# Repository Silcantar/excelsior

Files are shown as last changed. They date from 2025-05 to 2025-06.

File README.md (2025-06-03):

# *Excelsior*
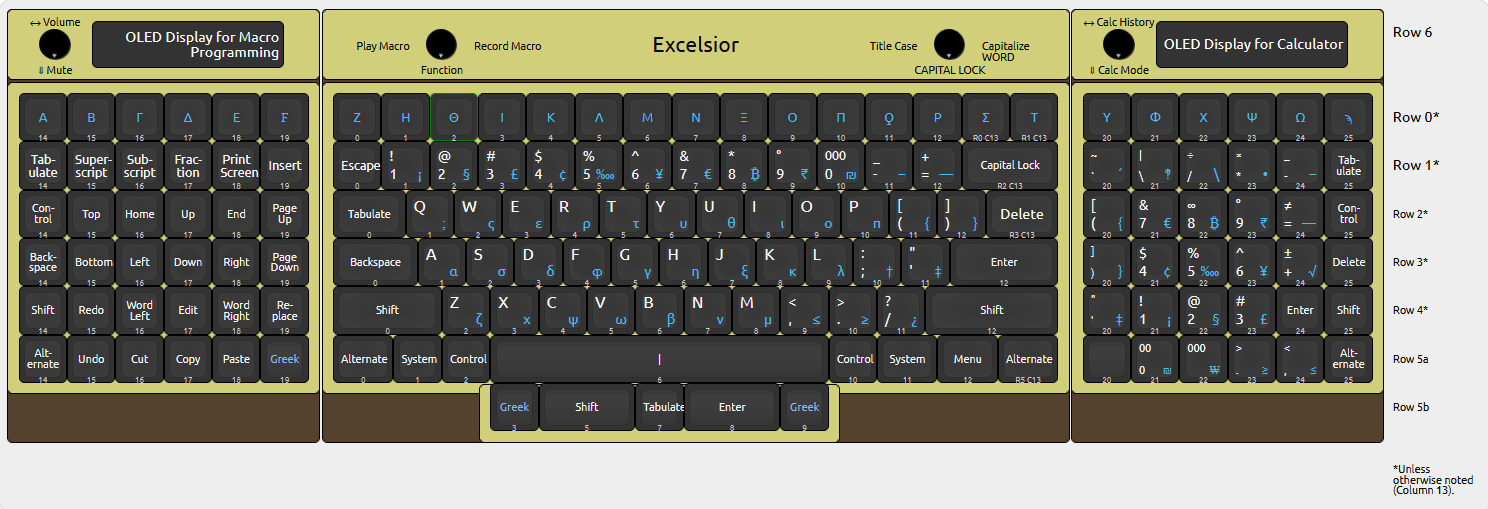
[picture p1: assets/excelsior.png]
Excelsior
>
>Tentative layout and design for *Excelsior*.

*Excelsior* is a 150% (153 keys) 3-section hand-wired keyboard (optionally) using uniform keycaps in a curved plate.

The main section is based on a standard ANSI 60% keyboard, but with a row of 15 function/programmable-macro keys at the top and 5 keys below the 7u spacebar.

The peripheral sections are each 6x6 ortholinear boards and can be placed on either side of the main section, including placing both on the same side of the main. They are connected to the main section by 20-pin pogo pin connectors either directly or via a custom cable. In the default keymap one section is an extended numpad and the other is a large navigation/macro pad. The top row of each peripheral is dedicated to additional function/programmable-macro keys for a total of 27.

The microcontroller is a Pimoroni PGA2350 board located in the main section. The matrix for the main section is wired directly to the controller board, while the I/O for the peripheral sections is handled by an MCP23017 I/O expander in each section communicating with the controller via I²C. The connections between the sections carry the signals necessary for both I²C and for SPI, plus several spare lines for interrupts, chip selects, or other I/O.

The matrix of the main section also has a seventh row that can be used for up to 14 momentary, toggle, or rotary switches on the top bezel of the keyboard. Note that the keys below the spacebar are on the sixth (spacebar) row of the matrix, so the seventh row is completely open.

Because of the massive number of GPIO pins on the PGA2350 and the I/O expanders, there is ample spare I/O for any functionality you could possibly want, from displays, encoders, LEDs, etc.

Because QMK does not currently support the RP2350 or displays larger than 128×64, I am planning to use KMK for the firmware.

For those interested, I have designed a [custom set](https://yuzukeycaps.com/c/4633754e-42e4-428c-9306-6221ce11477c)[^1] of KAM keycaps with a white-on-black-with-blue-accents *Wall Street Journal*-inspired aesthetic for *Excelsior* at YUZU Keycaps. They also feature secondary legends for a Greek alphabet/symbol layer and the macro keys are labeled with Greek numerals. There are a number of extra keys for alternative layouts too. Since the keycaps have a uniform profile any key can be placed on any row.

[^1]: If the link does not work, you can import [this JSON file](keycaps/Excelsior.json) to YUZU

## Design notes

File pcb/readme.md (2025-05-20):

This is a hand-wired build, so the "PCBs" here are not meant for production. I am using them to select and record the necessary components and to verify that the wiring topology is feasible.

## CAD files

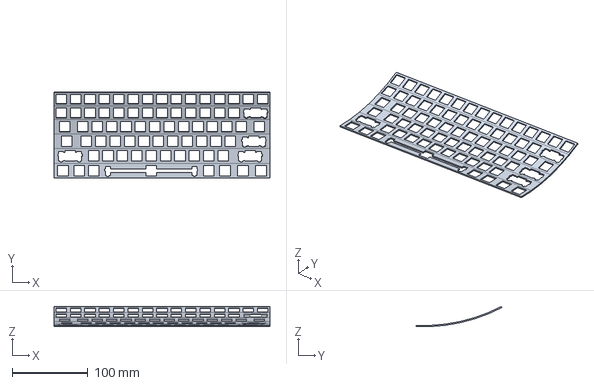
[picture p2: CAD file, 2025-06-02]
case/case.FCStd
285.0 x 113.6 x 26.6 mm

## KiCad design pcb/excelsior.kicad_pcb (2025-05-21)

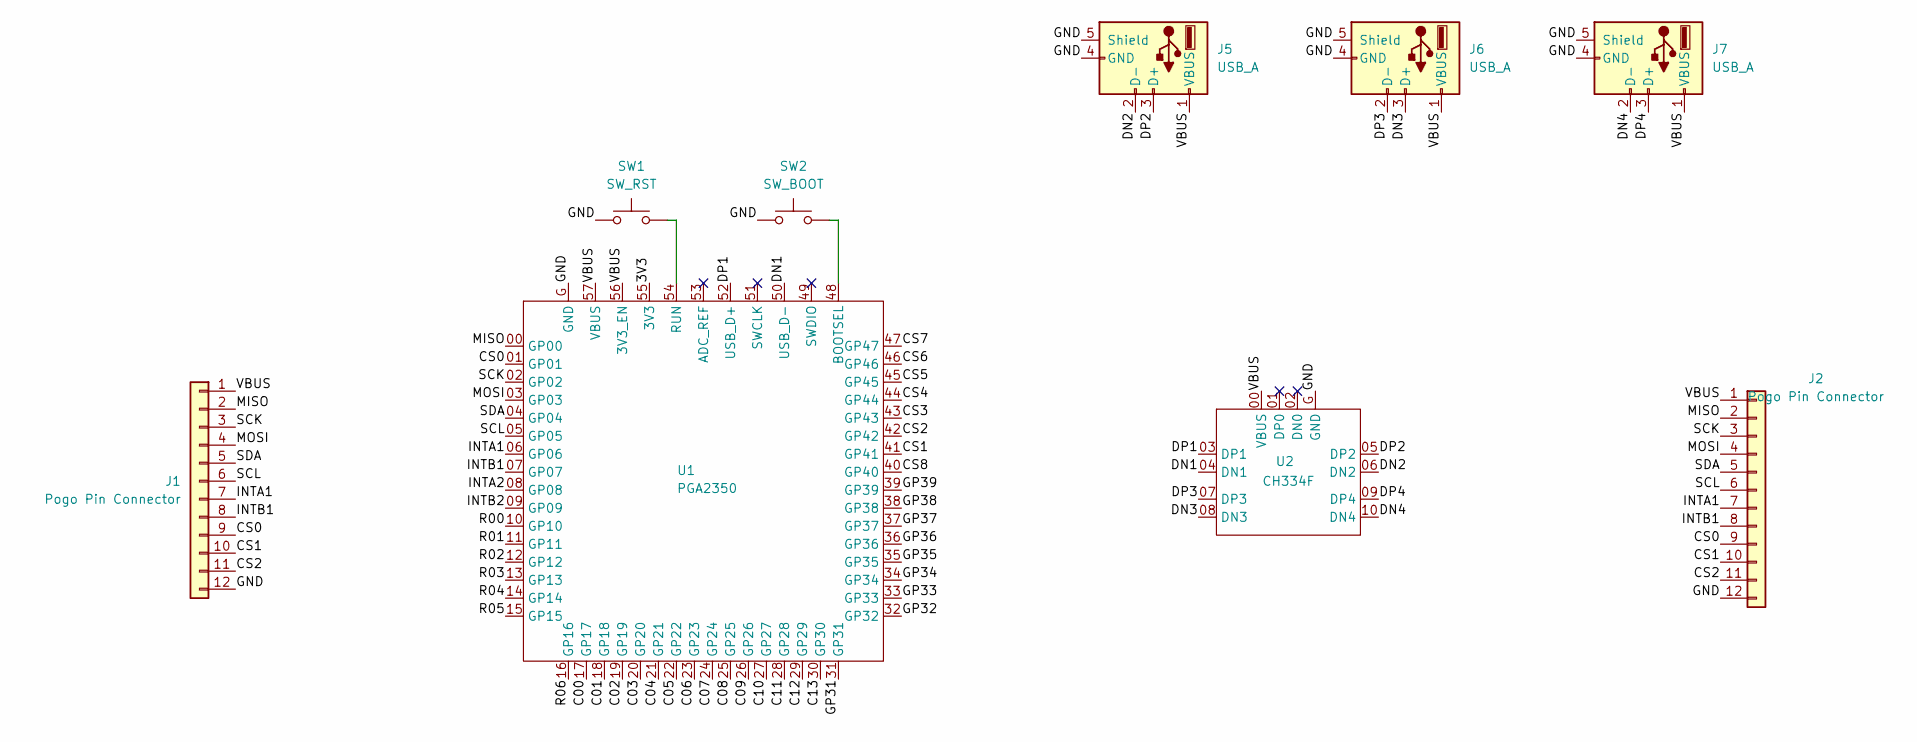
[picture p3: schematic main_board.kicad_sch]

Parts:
J1, J2: Pogo Pin Connector; PinHeader_1x12_P2.54mm_Vertical
J5, J6, J7: USB_A; USB_A_Molex_67643_Horizontal
SW1: SW_RST; SW_PUSH_6mm
SW2: SW_BOOT; SW_PUSH_6mm
U1: PGA2350
U2: CH334F; USB_Hub

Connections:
/Main Board/3V3: U1.55 (3V3)
/Main Board/C00: U1.17 (GP17)
/Main Board/C01: U1.18 (GP18)
/Main Board/C02: U1.19 (GP19)
/Main Board/C03: U1.20 (GP20)
/Main Board/C04: U1.21 (GP21)
/Main Board/C05: U1.22 (GP22)
/Main Board/C06: U1.23 (GP23)
/Main Board/C07: U1.24 (GP24)
/Main Board/C08: U1.25 (GP25)
/Main Board/C09: U1.26 (GP26)
/Main Board/C10: U1.27 (GP27)
/Main Board/C11: U1.28 (GP28)
/Main Board/C12: U1.29 (GP29)
/Main Board/C13: U1.30 (GP30)
/Main Board/CS0: J1.9, J2.9, U1.01 (GP01)
/Main Board/CS1: J1.10, J2.10, U1.41 (GP41)
/Main Board/CS2: J1.11, J2.11, U1.42 (GP42)
/Main Board/CS3: U1.43 (GP43)
/Main Board/CS4: U1.44 (GP44)
/Main Board/CS5: U1.45 (GP45)
/Main Board/CS6: U1.46 (GP46)
/Main Board/CS7: U1.47 (GP47)
/Main Board/CS8: U1.40 (GP40)
/Main Board/DN1: U1.50 (USB_D-), U2.04 (DN1)
/Main Board/DN2: J5.2 (D-), U2.06 (DN2)
/Main Board/DN3: J6.3 (D+), U2.08 (DN3)
/Main Board/DN4: J7.2 (D-), U2.10 (DN4)
/Main Board/DP1: U1.52 (USB_D+), U2.03 (DP1)
/Main Board/DP2: J5.3 (D+), U2.05 (DP2)
/Main Board/DP3: J6.2 (D-), U2.07 (DP3)
/Main Board/DP4: J7.3 (D+), U2.09 (DP4)
/Main Board/GND: J1.12, J2.12, J5.4 (GND), J5.5 (Shield), J6.4 (GND), J6.5 (Shield), J7.4 (GND), J7.5 (Shield), SW1.1, SW2.1, U1.G (GND), U2.G (GND)
/Main Board/GP31: U1.31 (GP31)
/Main Board/GP32: U1.32 (GP32)
/Main Board/GP33: U1.33 (GP33)
/Main Board/GP34: U1.34 (GP34)
/Main Board/GP35: U1.35 (GP35)
/Main Board/GP36: U1.36 (GP36)
/Main Board/GP37: U1.37 (GP37)
/Main Board/GP38: U1.38 (GP38)
/Main Board/GP39: U1.39 (GP39)
/Main Board/INTA1: J1.7, J2.7, U1.06 (GP06)
/Main Board/INTA2: U1.08 (GP08)
/Main Board/INTB1: J1.8, J2.8, U1.07 (GP07)
/Main Board/INTB2: U1.09 (GP09)
/Main Board/MISO: J1.2, J2.2, U1.00 (GP00)
/Main Board/MOSI: J1.4, J2.4, U1.03 (GP03)
/Main Board/R00: U1.10 (GP10)
/Main Board/R01: U1.11 (GP11)
/Main Board/R02: U1.12 (GP12)
/Main Board/R03: U1.13 (GP13)
/Main Board/R04: U1.14 (GP14)
/Main Board/R05: U1.15 (GP15)
/Main Board/R06: U1.16 (GP16)
/Main Board/SCK: J1.3, J2.3, U1.02 (GP02)
/Main Board/SCL: J1.6, J2.6, U1.05 (GP05)
/Main Board/SDA: J1.5, J2.5, U1.04 (GP04)
/Main Board/VBUS: J1.1, J2.1, J5.1 (VBUS), J6.1 (VBUS), J7.1 (VBUS), U1.56 (3V3_EN), U1.57 (VBUS), U2.00 (VBUS)
unnamed: SW2.2, U1.48 (BOOTSEL)
unnamed: SW1.2, U1.54 (RUN)

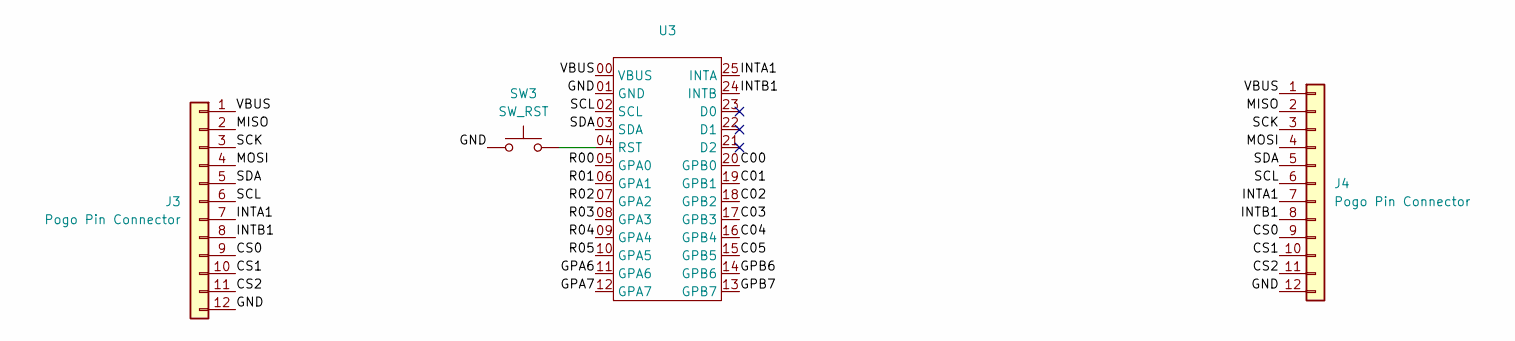
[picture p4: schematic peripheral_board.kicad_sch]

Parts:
J3, J4: Pogo Pin Connector; PinHeader_1x12_P2.54mm_Vertical
SW3: SW_RST; SW_PUSH_6mm
U3: MCP23017_Breakout

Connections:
/Peripheral Board/C00: U3.20 (GPB0)
/Peripheral Board/C01: U3.19 (GPB1)
/Peripheral Board/C02: U3.18 (GPB2)
/Peripheral Board/C03: U3.17 (GPB3)
/Peripheral Board/C04: U3.16 (GPB4)
/Peripheral Board/C05: U3.15 (GPB5)
/Peripheral Board/CS0: J3.9, J4.9
/Peripheral Board/CS1: J3.10, J4.10
/Peripheral Board/CS2: J3.11, J4.11
/Peripheral Board/GND: J3.12, J4.12, SW3.1, U3.01 (GND)
/Peripheral Board/GPA6: U3.11 (GPA6)
/Peripheral Board/GPA7: U3.12 (GPA7)
/Peripheral Board/GPB6: U3.14 (GPB6)
/Peripheral Board/GPB7: U3.13 (GPB7)
/Peripheral Board/INTA1: J3.7, J4.7, U3.25 (INTA)
/Peripheral Board/INTB1: J3.8, J4.8, U3.24 (INTB)
/Peripheral Board/MISO: J3.2, J4.2
/Peripheral Board/MOSI: J3.4, J4.4
/Peripheral Board/R00: U3.05 (GPA0)
/Peripheral Board/R01: U3.06 (GPA1)
/Peripheral Board/R02: U3.07 (GPA2)
/Peripheral Board/R03: U3.08 (GPA3)
/Peripheral Board/R04: U3.09 (GPA4)
/Peripheral Board/R05: U3.10 (GPA5)
/Peripheral Board/SCK: J3.3, J4.3
/Peripheral Board/SCL: J3.6, J4.6, U3.02 (SCL)
/Peripheral Board/SDA: J3.5, J4.5, U3.03 (SDA)
/Peripheral Board/VBUS: J3.1, J4.1, U3.00 (VBUS)
unnamed: SW3.2, U3.04 (RST)

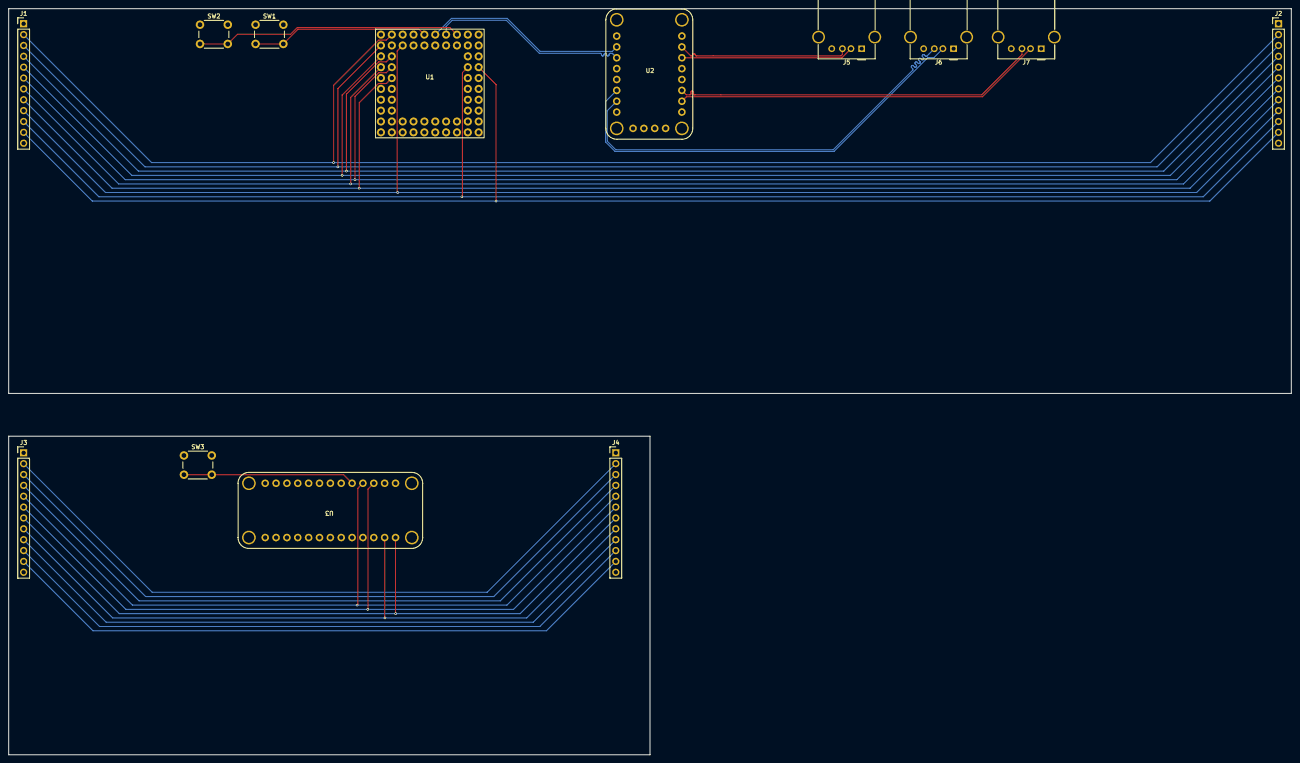
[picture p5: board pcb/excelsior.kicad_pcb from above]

Board: 4 copper layers, 300.0 x 174.5 mm, 13 parts (0 on the bottom side), 35 nets.

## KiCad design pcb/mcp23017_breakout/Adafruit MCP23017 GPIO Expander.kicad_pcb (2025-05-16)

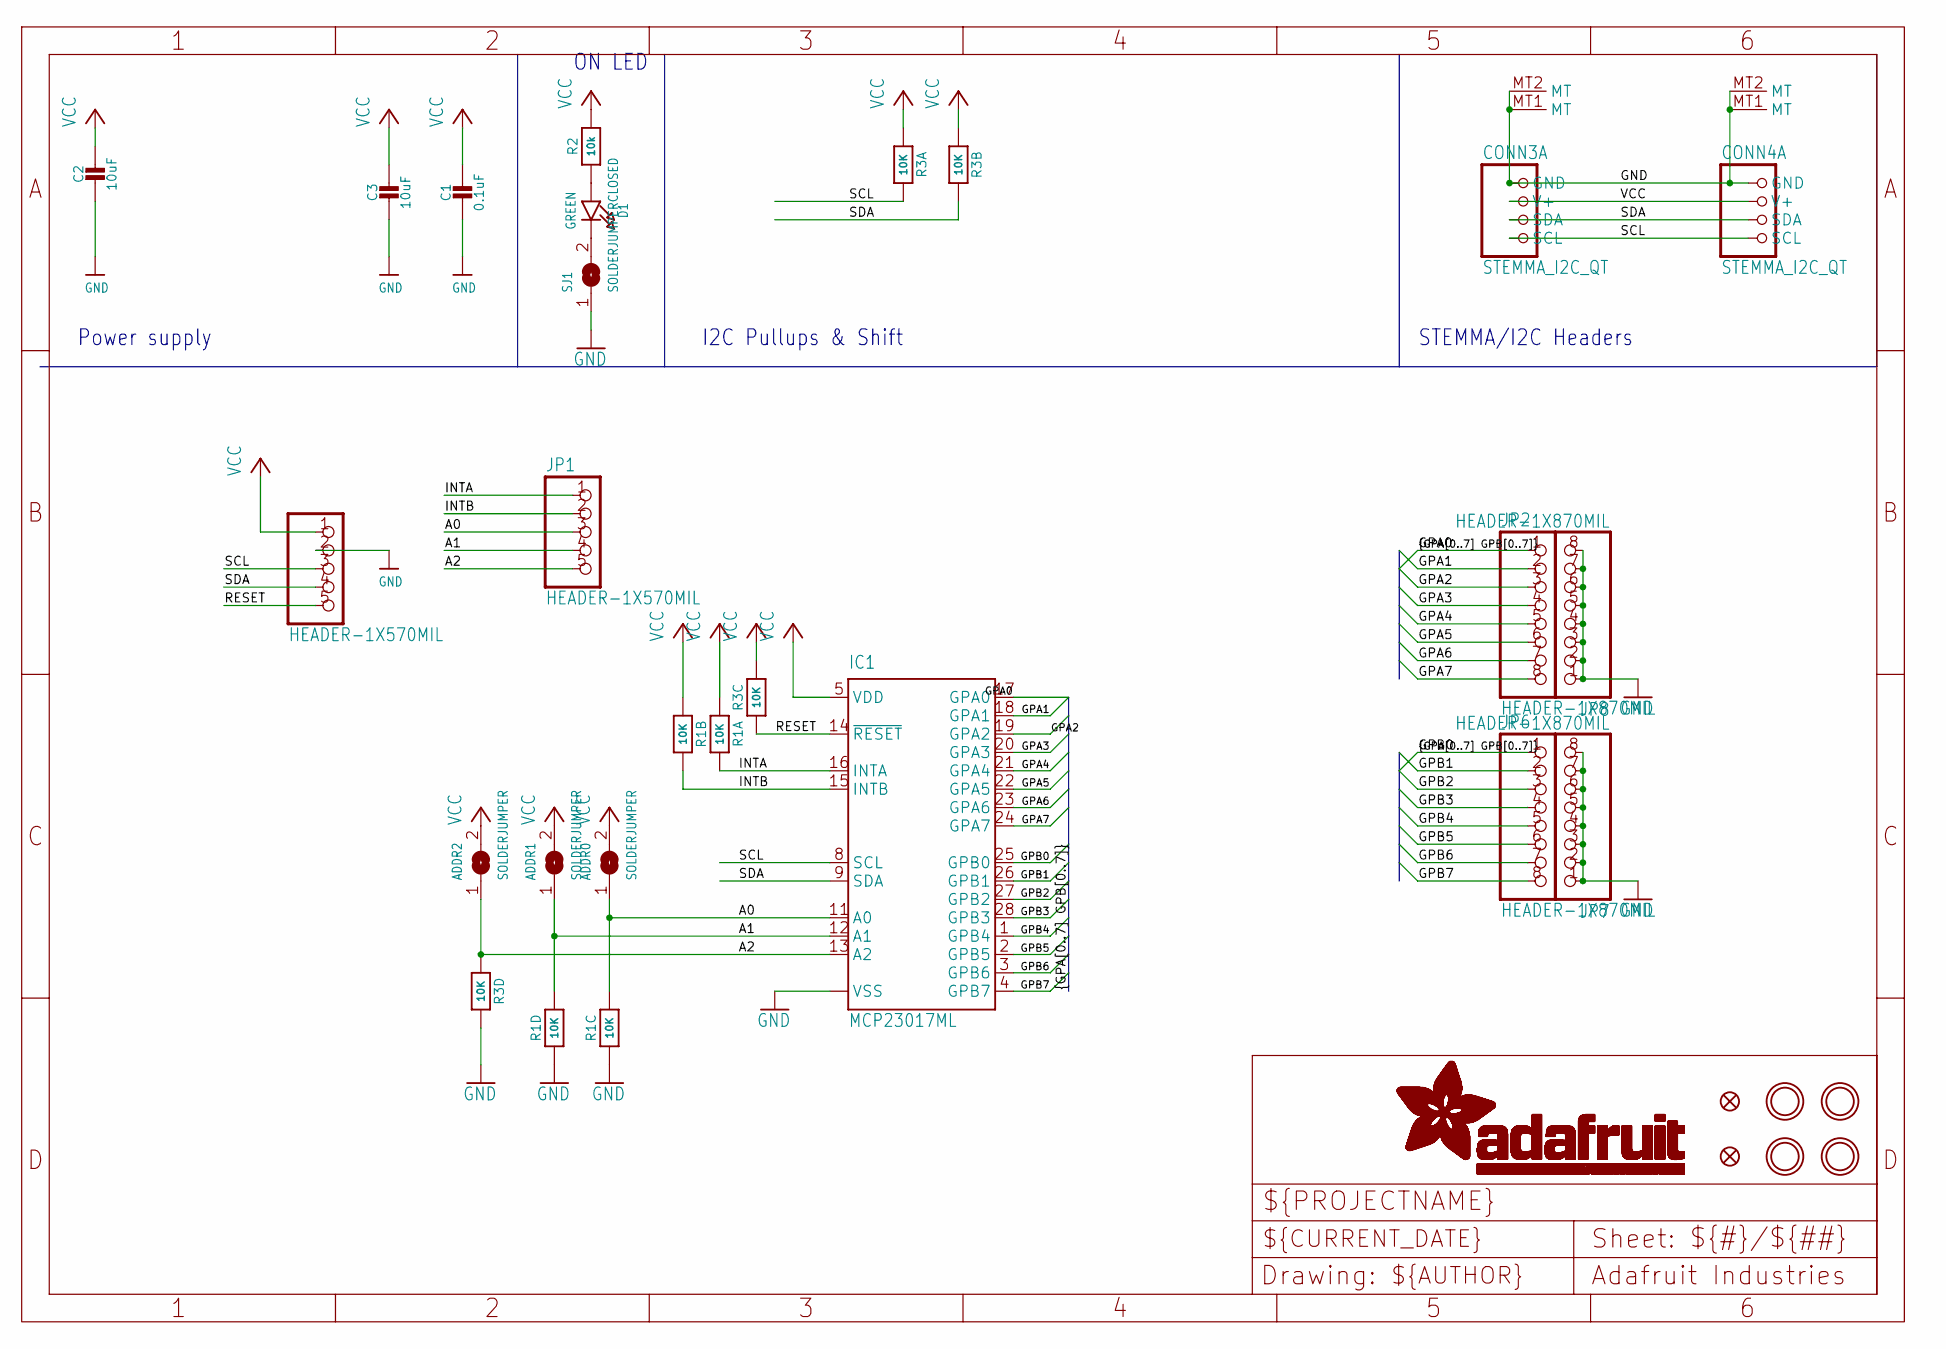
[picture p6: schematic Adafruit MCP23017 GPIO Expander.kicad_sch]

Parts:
ADDR0, ADDR1, ADDR2: SOLDERJUMPER; SOLDERJUMPER_ARROW_NOPASTE
C1: 0.1uF; 0603-NO
C2, C3: 10uF; 0805-NO
CONN3, CONN4: STEMMA_I2C_QT; JST_SH4
D1: GREEN; CHIPLED_0603_NOOUTLINE
FID3, FID4: FIDUCIAL_1MM
IC1: MCP23017ML; QFN28-ML_6X6MM
JP1, JP5: HEADER-1X570MIL; 1X05_ROUND_70
JP2, JP6, JP7, JP8: HEADER-1X870MIL; 1X08_ROUND_70
R1, R3: 10K; RESPACK_4X0603
R2: 10k; 0603-NO
SJ1: SOLDERJUMPERCLOSED; SOLDERJUMPER_CLOSEDWIRE
U$1, U$17, U$19, U$21: MOUNTINGHOLE2.5; MOUNTINGHOLE_2.5_PLATED

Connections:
A0: ADDR0.1, IC1.11 (A0), JP1.3, R1.6 (2)
A1: ADDR1.1, IC1.12 (A1), JP1.4, R1.5 (2)
A2: ADDR2.1, IC1.13 (A2), JP1.5, R3.4 (1)
GND: C1.2, C2.2, C3.2, CONN3.1 (GND), CONN3.MT1 (MT), CONN3.MT2 (MT), CONN4.1 (GND), CONN4.MT1 (MT), CONN4.MT2 (MT), IC1.6 (VSS), IC1.EXP (VSS), JP5.2, JP7.1, JP7.2, JP7.3, JP7.4, JP7.5, JP7.6, JP7.7, JP7.8, JP8.1, JP8.2, JP8.3, JP8.4, JP8.5, JP8.6, JP8.7, JP8.8, R1.3 (1), R1.4 (1), R3.5 (2), SJ1.1
GPA1: IC1.18 (GPA1), JP2.2
GPA2: IC1.19 (GPA2), JP2.3
GPA3: IC1.20 (GPA3), JP2.4
GPA4: IC1.21 (GPA4), JP2.5
GPA5: IC1.22 (GPA5), JP2.6
GPA6: IC1.23 (GPA6), JP2.7
GPA7: IC1.24 (GPA7), JP2.8
GPB1: IC1.26 (GPB1), JP6.2
GPB2: IC1.27 (GPB2), JP6.3
GPB3: IC1.28 (GPB3), JP6.4
GPB4: IC1.1 (GPB4), JP6.5
GPB5: IC1.2 (GPB5), JP6.6
GPB6: IC1.3 (GPB6), JP6.7
GPB7: IC1.4 (GPB7), JP6.8
INTA: IC1.16 (INTA), JP1.1, R1.8 (2)
INTB: IC1.15 (INTB), JP1.2, R1.7 (2)
unnamed: D1.A, R2.1
unnamed: D1.C, SJ1.2
RESET: IC1.14 (~RESET), JP5.5, R3.3 (1)
SCL: CONN3.4 (SCL), CONN4.4 (SCL), IC1.8 (SCL), JP5.3, R3.8 (2)
SDA: CONN3.3 (SDA), CONN4.3 (SDA), IC1.9 (SDA), JP5.4, R3.7 (2)
VCC: ADDR0.2, ADDR1.2, ADDR2.2, C1.1, C2.1, C3.1, CONN3.2 (V+), CONN4.2 (V+), IC1.5 (VDD), JP5.1, R1.1, R1.2 (1), R2.2, R3.1, R3.2 (1), R3.6 (2)

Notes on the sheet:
ON LED
Power supply
I2C Pullups & Shift
STEMMA/I2C Headers

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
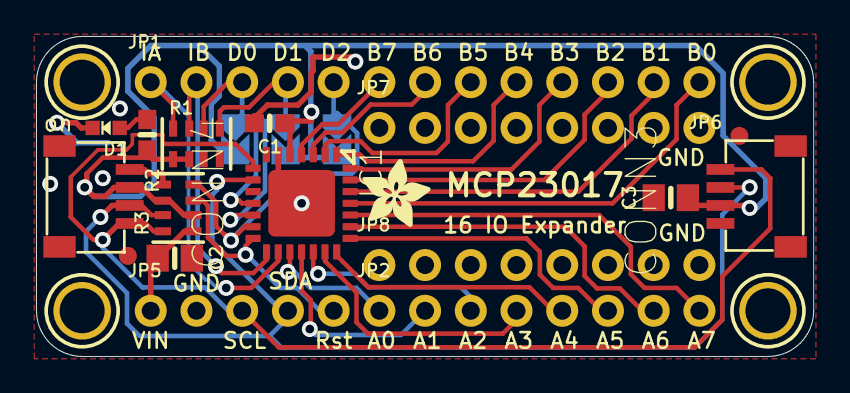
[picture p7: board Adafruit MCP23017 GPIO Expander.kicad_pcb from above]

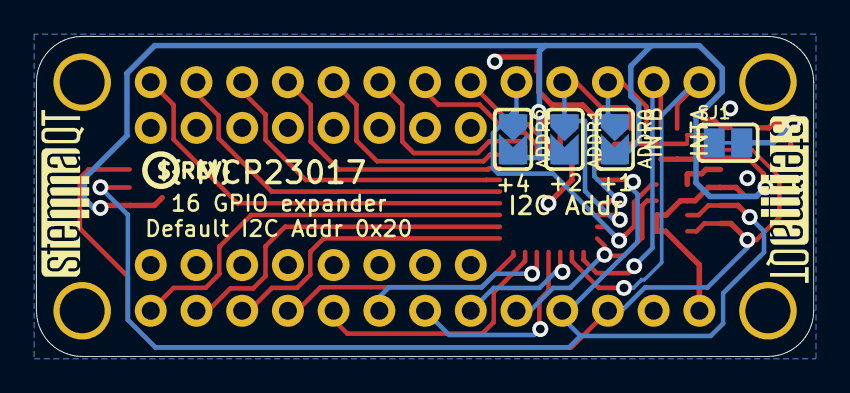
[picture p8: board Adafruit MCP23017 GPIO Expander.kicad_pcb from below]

Board: 2 copper layers, 43.2 x 17.8 mm, 30 parts (7 on the bottom side), 28 nets.

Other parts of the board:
U$22: ADAFRUIT_3.5MM
U$25: PCBFEAT-REV-040
U$30, U$31: STEMMAQT

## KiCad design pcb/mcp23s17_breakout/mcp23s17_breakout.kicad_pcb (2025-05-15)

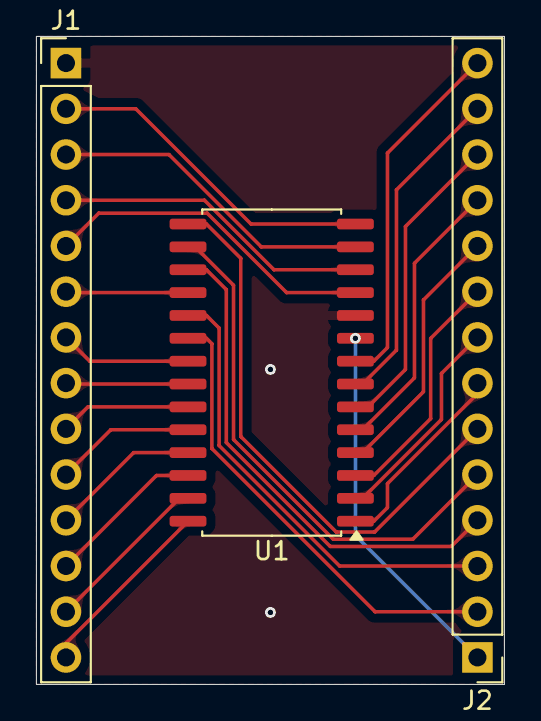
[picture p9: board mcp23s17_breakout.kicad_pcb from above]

Board: 2 copper layers, 26.0 x 36.0 mm, 3 parts (0 on the bottom side), 28 nets.

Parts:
J1, J2: Conn_01x14; PinHeader_1x14_P2.54mm_Vertical
U1: MCP23017_SO; SOIC-28W_7.5x17.9mm_P1.27mm

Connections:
/A0: J2.19 (Pin_6), U1.15 (A0)
/A1: J2.18 (Pin_5), U1.16 (A1)
/A2: J2.17 (Pin_4), U1.17 (A2)
/CS: J1.04 (Pin_5), U1.11 (~CS)
/GND: J1.G (Pin_1), U1.10 (VSS)
/GPA0: J1.06 (Pin_7), U1.21 (GPA0)
/GPA1: J1.07 (Pin_8), U1.22 (GPA1)
/GPA2: J1.08 (Pin_9), U1.23 (GPA2)
/GPA3: J1.09 (Pin_10), U1.24 (GPA3)
/GPA4: J1.10 (Pin_11), U1.25 (GPA4)
/GPA5: J1.11 (Pin_12), U1.26 (GPA5)
/GPA6: J1.12 (Pin_13), U1.27 (GPA6)
/GPA7: J1.13 (Pin_14), U1.28 (GPA7)
/GPB0: J2.20 (Pin_7), U1.1 (GPB0)
/GPB1: J2.21 (Pin_8), U1.2 (GPB1)
/GPB2: J2.22 (Pin_9), U1.3 (GPB2)
/GPB3: J2.23 (Pin_10), U1.4 (GPB3)
/GPB4: J2.24 (Pin_11), U1.5 (GPB4)
/GPB5: J2.25 (Pin_12), U1.6 (GPB5)
/GPB6: J2.26 (Pin_13), U1.7 (GPB6)
/GPB7: J2.27 (Pin_14), U1.8 (GPB7)
/INTA: J2.15 (Pin_2), U1.20 (INTA)
/INTB: J2.16 (Pin_3), U1.19 (INTB)
/RST: J1.05 (Pin_6), U1.18 (~RESET)
/SCK: J1.03 (Pin_4), U1.12 (SCK)
/SI: J1.02 (Pin_3), U1.13 (SI)
/SO: J1.01 (Pin_2), U1.14 (SO)
/VBUS: J2.14 (Pin_1), U1.9 (VDD)

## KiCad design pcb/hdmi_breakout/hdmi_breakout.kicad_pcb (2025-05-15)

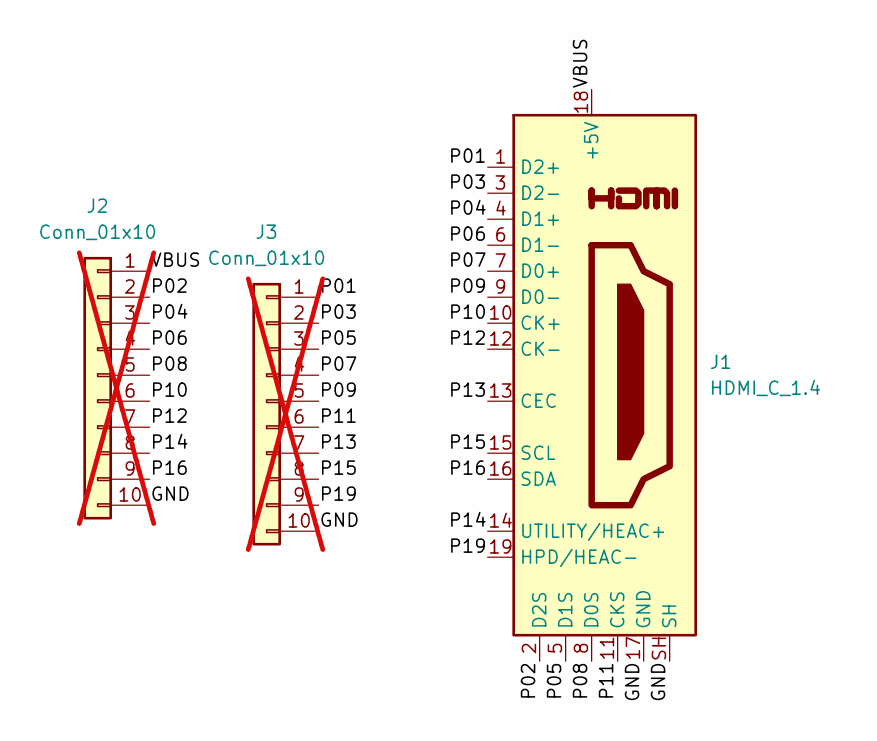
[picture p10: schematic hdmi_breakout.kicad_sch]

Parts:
J1: HDMI_C_1.4; HDMI_A_Molex_208658-1001_Horizontal
J2, J3: Conn_01x10; PinHeader_1x10_P2.54mm_Vertical; not fitted

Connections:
/GND: J1.17 (GND), J1.SH, J2.10, J3.10
/P01: J1.1 (D2+), J3.1
/P02: J1.2 (D2S), J2.2
/P03: J1.3 (D2-), J3.2
/P04: J1.4 (D1+), J2.3
/P05: J1.5 (D1S), J3.3
/P06: J1.6 (D1-), J2.4
/P07: J1.7 (D0+), J3.4
/P08: J1.8 (D0S), J2.5
/P09: J1.9 (D0-), J3.5
/P10: J1.10 (CK+), J2.6
/P11: J1.11 (CKS), J3.6
/P12: J1.12 (CK-), J2.7
/P13: J1.13 (CEC), J3.7
/P14: J1.14 (UTILITY/HEAC+), J2.8
/P15: J1.15 (SCL), J3.8
/P16: J1.16 (SDA), J2.9
/P19: J1.19 (HPD/HEAC-), J3.9
/VBUS: J1.18 (+5V), J2.1

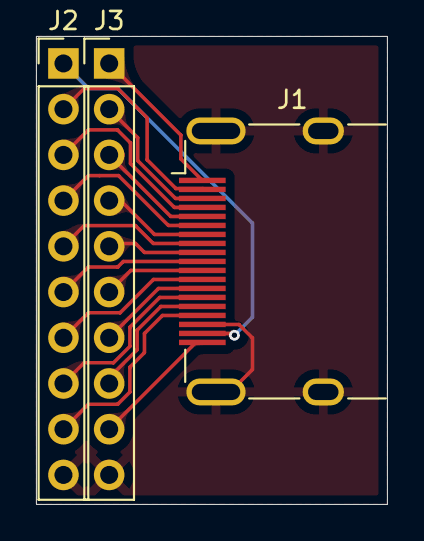
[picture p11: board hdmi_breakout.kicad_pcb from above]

Board: 2 copper layers, 19.5 x 26.0 mm, 3 parts (0 on the bottom side), 19 nets.

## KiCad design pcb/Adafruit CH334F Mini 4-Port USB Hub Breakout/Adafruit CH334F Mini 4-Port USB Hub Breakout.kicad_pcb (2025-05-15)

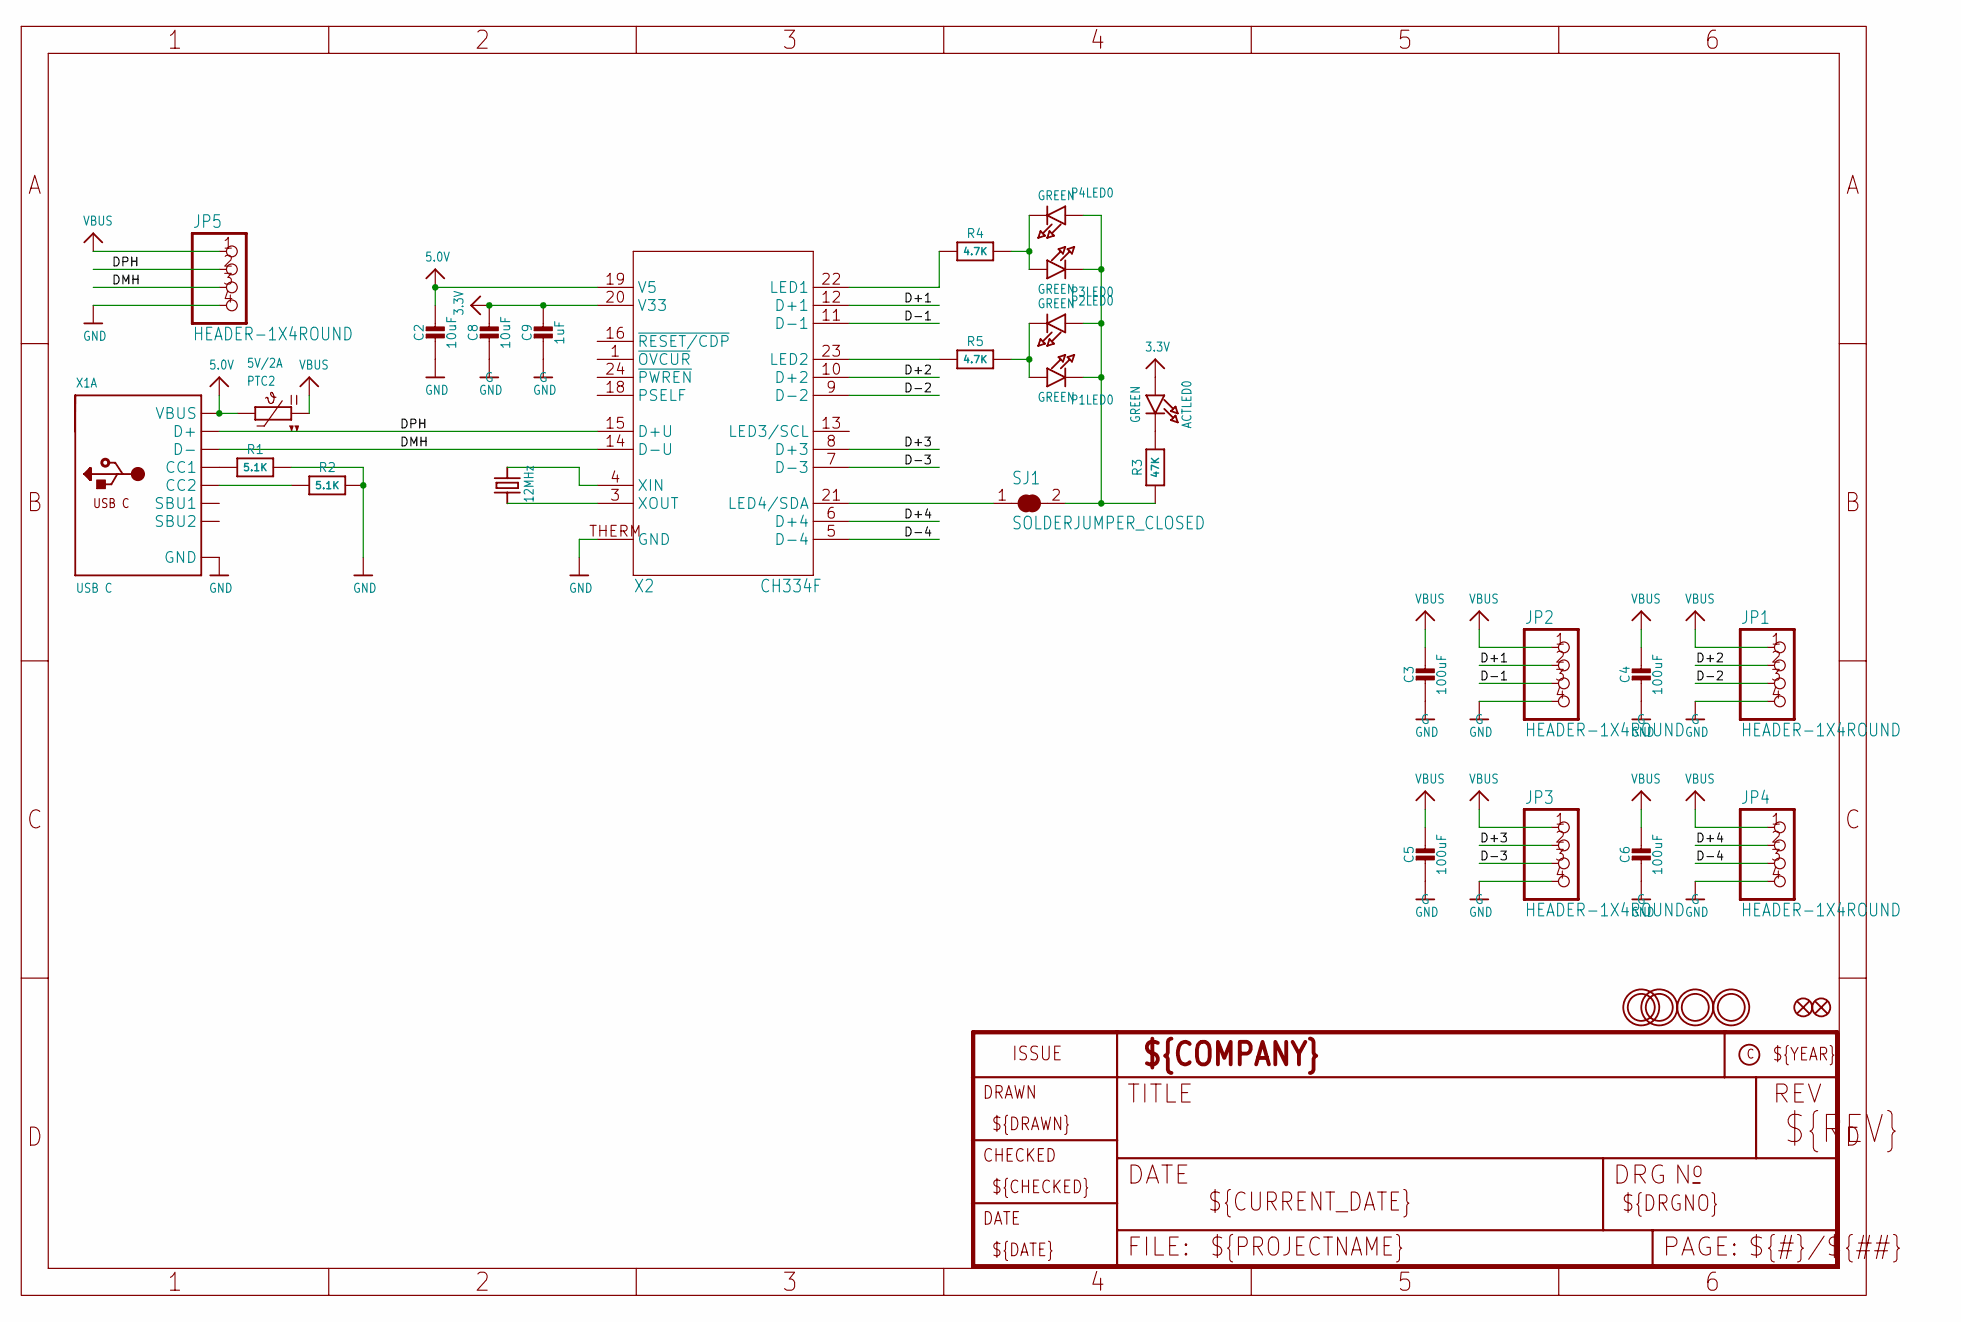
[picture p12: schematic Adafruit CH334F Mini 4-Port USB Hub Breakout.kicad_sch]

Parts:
ACTLED0: GREEN; CHIPLED_0603_NOOUTLINE
C2, C8: 10uF; 0805-NO
C3, C4, C5, C6: 100uF; _1206
C9: 1uF; 0603-NO
FID1, FID2: FIDUCIAL_0.5MM
JP1, JP2, JP3, JP4, JP5: HEADER-1X4ROUND; 1X04_ROUND
P1LED0, P2LED0, P3LED0, P4LED0: GREEN; CHIPLED_0603_NOOUTLINE
PTC2: 5V/2A; 0805-NO
R1, R2: 5.1K; 0603-NO
R3: 47K; 0603-NO
R4, R5: 4.7K; 0603-NO
SJ1: SOLDERJUMPER_CLOSED; SOLDERJUMPER_CLOSEDWIRE
U$23, U$28, U$29, U$31: MOUNTINGHOLE2.5; MOUNTINGHOLE_2.5_PLATED
X1: USB C; USB_C_CUSB31-CFM2AX-01-X
X2: CH334F; QFN24_4MM
Y1: 12MHz; CRYSTAL_2.5X2

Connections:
3.3V: ACTLED0.A, C8.1, C9.1, X2.20 (V33)
5.0V: C2.1, PTC2.2, X1.A4B9 (VBUS), X1.B4A9 (VBUS), X2.19 (V5)
D+1: JP2.2, X2.12 (D+1)
D+2: JP1.2, X2.10 (D+2)
D+3: JP3.2, X2.8 (D+3)
D+4: JP4.2, X2.6 (D+4)
D-1: JP2.3, X2.11 (D-1)
D-2: JP1.3, X2.9 (D-2)
D-3: JP3.3, X2.7 (D-3)
D-4: JP4.3, X2.5 (D-4)
DMH: JP5.3, X1.A7 (D-), X1.B7 (D-), X2.14 (D-U)
DPH: JP5.2, X1.A6 (D+), X1.B6 (D+), X2.15 (D+U)
GND: C2.2, C3.2, C4.2, C5.2, C6.2, C8.2, C9.2, JP1.4, JP2.4, JP3.4, JP4.4, JP5.4, R1.2, R2.2, X1.A1B12 (GND), X1.B1A12 (GND), X2.THERM (GND)
unnamed: R1.1, X1.A5 (CC1)
unnamed: R2.1, X1.B5 (CC2)
unnamed: X2.3 (XOUT), Y1.1
unnamed: X2.4 (XIN), Y1.3 (2)
unnamed: ACTLED0.C, R3.2
unnamed: P1LED0.C, P2LED0.A, P3LED0.C, P4LED0.A, R3.1, SJ1.2
unnamed: P3LED0.A, P4LED0.C, R4.2
unnamed: R4.1, X2.22 (LED1)
unnamed: SJ1.1, X2.21 (LED4/SDA)
unnamed: P1LED0.A, P2LED0.C, R5.2
unnamed: R5.1, X2.23 (LED2)
VBUS: C3.1, C4.1, C5.1, C6.1, JP1.1, JP2.1, JP3.1, JP4.1, JP5.1, PTC2.1

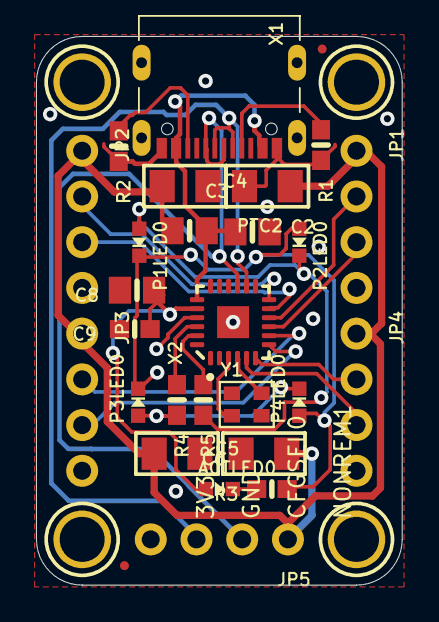
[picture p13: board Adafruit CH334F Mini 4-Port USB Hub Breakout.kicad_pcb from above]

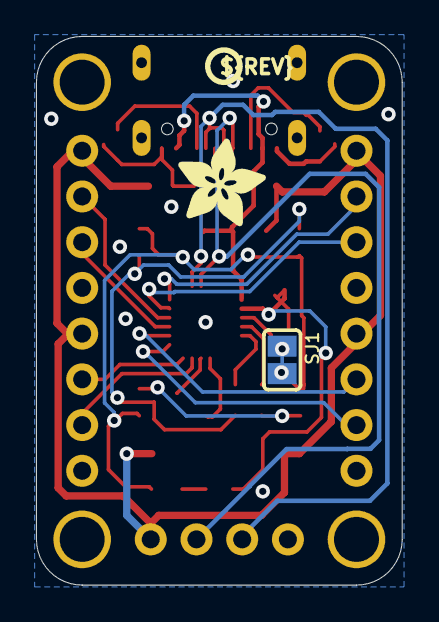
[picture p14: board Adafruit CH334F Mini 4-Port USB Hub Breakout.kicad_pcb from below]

Board: 2 copper layers, 20.3 x 30.5 mm, 68 parts (11 on the bottom side), 25 nets.

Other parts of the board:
PLABEL0: PLABEL0
PLABEL1: PLABEL1
PLABEL2: PLABEL2
PLABEL3: PLABEL3
PLABEL4: PLABEL4
PLABEL5: PLABEL5
PLABEL6: PLABEL6
PLABEL7: PLABEL7
PLABEL8: PLABEL8
PLABEL9: PLABEL9
PLABEL10: PLABEL10
PLABEL11: PLABEL11
PLABEL12: PLABEL12
PLABEL13: PLABEL13
PLABEL14: PLABEL14
PLABEL15: PLABEL15
PLABEL16: PLABEL16
PLABEL17: PLABEL17
PLABEL18: PLABEL18
PLABEL19: PLABEL19
PLABEL20: PLABEL20
PLABEL21: PLABEL21
PLABEL22: PLABEL22
PLABEL23: PLABEL23
PLABEL24: PLABEL24
PLABEL25: PLABEL25
PLABEL26: PLABEL26
PLABEL27: PLABEL27
PLABEL28: PLABEL28
PLABEL29: PLABEL29
PLABEL30: PLABEL30
PLABEL31: PLABEL31
PLABEL32: PLABEL32
U$33: ADAFRUIT_5MM
U$34: PCBFEAT-REV-040

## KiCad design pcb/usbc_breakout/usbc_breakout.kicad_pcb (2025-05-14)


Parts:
J2, J3: Conn_01x05; PinHeader_1x05_P2.54mm_Vertical
P1: USB_C_Receptacle; USB_C_Receptacle_JAE_DX07S024WJ3R400

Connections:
/GND: J2.1, P1.A1 (GND), P1.A12 (GND), P1.B1 (GND), P1.B12 (GND), P1.S1 (SHIELD)
/P02: J2.2, P1.A2 (TX1+), P1.B2 (TX2+)
/P03: J2.3, P1.A3 (TX1-), P1.B3 (TX2-)
/P05: J2.4, P1.A5 (CC1), P1.B5 (CC2)
/P06: J2.5, P1.A6 (D+), P1.B6 (D+)
/P07: J3.2, P1.A7 (D-), P1.B7 (D-)
/P08: J3.3, P1.A8 (SBU1), P1.B8 (SBU2)
/P10: J3.4, P1.A10 (RX2-), P1.B10 (RX1-)
/P11: J3.5, P1.A11 (RX2+), P1.B11 (RX1+)
/VBUS: J3.1, P1.A4 (VBUS), P1.A9 (VBUS), P1.B4 (VBUS), P1.B9 (VBUS)


Board: 2 copper layers, 15.0 x 19.0 mm, 3 parts (0 on the bottom side), 10 nets.

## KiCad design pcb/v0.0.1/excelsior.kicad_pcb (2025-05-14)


Board: 2 copper layers, 301.0 x 54.0 mm, 19 parts (0 on the bottom side), 74 nets.

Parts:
J5: Conn_01x40_Socket; PinHeader_1x32_P2.54mm_Vertical
J5_0, J5_0#2, J5_1, J5_1#2: Conn_01x12; PinHeader_1x05_P2.54mm_Vertical
J6: USB_Hub4_FDD; USB_A_Molex_67643_Horizontal
J7: USB_Hub3; USB_A_Molex_67643_Horizontal
J8: USB_Hub2; USB_A_Molex_67643_Horizontal
J9: Conn_01x16_Socket; PinHeader_1x32_P2.54mm_Vertical
P4: Left_Peripheral; USB_C_Receptacle_Amphenol_12401548E4-2A
P5: Host_Port; USB_C_Receptacle_Amphenol_12401548E4-2A
P6: Right_Peripheral; USB_C_Receptacle_Amphenol_12401548E4-2A
P10, P10#2: USB_C_Receptacle; USB_C_Receptacle_JAE_DX07S024WJ3R400
SW2, SW3, SW4: SW_Push; SW_SPST_EVPBF
U4: PGA2350; pga2350
U5: CH334R; QSOP-16_3.9x4.9mm_P0.635mm

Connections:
/Excelsior_PGA2350/3V3: J9.31, U4.3V3
/Excelsior_PGA2350/BOOT: SW4.2, U4.BS (BOOTSEL)
/Excelsior_PGA2350/CH_RST: SW2.2, U5.9 (~RESET/CDP)
/Excelsior_PGA2350/CS: J5.8, P4.A3 (TX1-), P4.B3 (TX2-), P6.A3 (TX1-), P6.B3 (TX2-), U4.05 (GP05)
/Excelsior_PGA2350/DM1+: U4.U+ (USB_D+), U5.8 (DP1+)
/Excelsior_PGA2350/DM1-: U4.U- (USB_D-), U5.7 (DM1-)
/Excelsior_PGA2350/DM2+: J8.3 (D+), U5.6 (DP2+)
/Excelsior_PGA2350/DM2-: J8.2 (D-), U5.5 (DM2-)
/Excelsior_PGA2350/DM3+: J7.3 (D+), U5.4 (DP3+)
/Excelsior_PGA2350/DM3-: J7.2 (D-), U5.3 (DM3-)
/Excelsior_PGA2350/DM4+: J6.3 (D+), U5.2 (DP4+)
/Excelsior_PGA2350/DM4-: J6.2 (D-), U5.1 (DM4-)
/Excelsior_PGA2350/GND: J5.1, J5.9, J5.17, J5.25, J6.4 (GND), J6.5 (Shield), J7.4 (GND), J7.5 (Shield), J8.4 (GND), J8.5 (Shield), J9.1, J9.9, J9.17, J9.25, J9.26, J9.27, J9.28, J9.29, J9.30, J9.32, P4.A1 (GND), P4.A12 (GND), P4.B1 (GND), P4.B12 (GND), P4.S1 (SHIELD), P5.A1 (GND), P5.A12 (GND), P5.B1 (GND), P5.B12 (GND), P5.S1 (SHIELD), P6.A1 (GND), P6.A12 (GND), P6.B1 (GND), P6.B12 (GND), P6.S1 (SHIELD), SW2.1, SW3.1, SW4.1, U4.G (GND), U5.14 (GND)
/Excelsior_PGA2350/GP06: J5.10, U4.06 (GP06)
/Excelsior_PGA2350/GP07: J5.11, U4.07 (GP07)
/Excelsior_PGA2350/GP08: J5.12, U4.08 (GP08)
/Excelsior_PGA2350/GP09: J5.13, U4.09 (GP09)
/Excelsior_PGA2350/GP10: J5.14, U4.10 (GP10)
/Excelsior_PGA2350/GP11: J5.15, U4.11 (GP11)
/Excelsior_PGA2350/GP12: J5.16, U4.12 (GP12)
/Excelsior_PGA2350/GP13: J5.18, U4.13 (GP13)
/Excelsior_PGA2350/GP14: J5.19, U4.14 (GP14)
/Excelsior_PGA2350/GP15: J5.20, U4.15 (GP15)
/Excelsior_PGA2350/GP16: J5.21, U4.16 (GP16)
/Excelsior_PGA2350/GP17: J5.22, U4.17 (GP17)
/Excelsior_PGA2350/GP18: J5.23, U4.18 (GP18)
/Excelsior_PGA2350/GP19: J5.24, U4.19 (GP19)
/Excelsior_PGA2350/GP20: J5.26, U4.20 (GP20)
/Excelsior_PGA2350/GP21: J5.27, U4.21 (GP21)
/Excelsior_PGA2350/GP22: J5.28, U4.22 (GP22)
/Excelsior_PGA2350/GP23: J5.29, U4.23 (GP23)
/Excelsior_PGA2350/GP24: J5.30, U4.24 (GP24)
/Excelsior_PGA2350/GP25: J5.31, U4.25 (GP25)
/Excelsior_PGA2350/GP26: J5.32, U4.26 (GP26)
/Excelsior_PGA2350/GP27: J9.2, U4.27 (GP27)
/Excelsior_PGA2350/GP28: J9.3, U4.28 (GP28)
/Excelsior_PGA2350/GP29: J9.4, U4.29 (GP29)
/Excelsior_PGA2350/GP30: J9.5, U4.30 (GP30)
/Excelsior_PGA2350/GP31: J9.6, U4.31 (GP31)
/Excelsior_PGA2350/GP32: J9.7, U4.32 (GP32)
/Excelsior_PGA2350/GP33: J9.8, U4.33 (GP33)
/Excelsior_PGA2350/GP34: J9.10, U4.34 (GP34)
/Excelsior_PGA2350/GP35: J9.11, U4.35 (GP35)
/Excelsior_PGA2350/GP36: J9.12, U4.36 (GP36)
/Excelsior_PGA2350/GP37: J9.13, U4.37 (GP37)
/Excelsior_PGA2350/GP38: J9.14, U4.38 (GP38)
/Excelsior_PGA2350/GP39: J9.15, U4.39 (GP39)
/Excelsior_PGA2350/GP40: J9.16, U4.40 (GP40)
/Excelsior_PGA2350/GP41: J9.18, U4.41 (GP41)
/Excelsior_PGA2350/GP42: J9.19, U4.42 (GP42)
/Excelsior_PGA2350/GP43: J9.20, U4.43 (GP43)
/Excelsior_PGA2350/GP44: J9.21, U4.44 (GP44)
/Excelsior_PGA2350/GP45: J9.22, U4.45 (GP45)
/Excelsior_PGA2350/GP46: J9.23, U4.46 (GP46)
/Excelsior_PGA2350/GP47: J9.24, U4.47 (GP47)
/Excelsior_PGA2350/HOST_D+: P5.A6 (D+), P5.B6 (D+), U5.11 (DPU+)
/Excelsior_PGA2350/HOST_D-: P5.A7 (D-), P5.B7 (D-), U5.10 (DMU-)
/Excelsior_PGA2350/INTA: J5.3, P4.A10 (RX2-), P4.B10 (RX1-), P6.A10 (RX2-), P6.B10 (RX1-), U4.00 (GP00)
/Excelsior_PGA2350/INTB: J5.4, P4.A11 (RX2+), P4.B11 (RX1+), P6.A11 (RX2+), P6.B11 (RX1+), U4.01 (GP01)
/Excelsior_PGA2350/MISO: J5.7, P4.A6 (D+), P4.B6 (D+), P6.A6 (D+), P6.B6 (D+), U4.04 (GP04)
/Excelsior_PGA2350/MOSI: J5.6, P4.A7 (D-), P4.B7 (D-), P6.A7 (D-), P6.B7 (D-), U4.03 (GP03)
/Excelsior_PGA2350/RESET: SW3.2, U4.R (RUN)
/Excelsior_PGA2350/SCK: J5.5, P4.A2 (TX1+), P4.B2 (TX2+), P6.A2 (TX1+), P6.B2 (TX2+), U4.02 (GP02)
/Excelsior_PGA2350/VBUS: J5.2, J6.1 (VBUS), J7.1 (VBUS), J8.1 (VBUS), P4.A4 (VBUS), P4.A9 (VBUS), P4.B4 (VBUS), P4.B9 (VBUS), P5.A4 (VBUS), P5.A9 (VBUS), P5.B4 (VBUS), P5.B9 (VBUS), P6.A4 (VBUS), P6.A9 (VBUS), P6.B4 (VBUS), P6.B9 (VBUS), U4.3EN (3V3_EN), U4.VBB (VBUS), U5.12 (V5)
/USB Breakout/2: J5_0.2, J5_0#2.2, P10.A2 (TX1+), P10.B2 (TX2+), P10#2.A2 (TX1+), P10#2.B2 (TX2+)
/USB Breakout/3: J5_0.3, J5_0#2.3, P10.A3 (TX1-), P10.B3 (TX2-), P10#2.A3 (TX1-), P10#2.B3 (TX2-)
/USB Breakout/5: J5_0.4, J5_0#2.4, P10.A5 (CC1), P10.B5 (CC2), P10#2.A5 (CC1), P10#2.B5 (CC2)
/USB Breakout/6: J5_0.5, J5_0#2.5, P10.A6 (D+), P10.B6 (D+), P10#2.A6 (D+), P10#2.B6 (D+)
/USB Breakout/7: J5_1.5, J5_1#2.5, P10.A7 (D-), P10.B7 (D-), P10#2.A7 (D-), P10#2.B7 (D-)
/USB Breakout/8: J5_1.4, J5_1#2.4, P10.A8 (SBU1), P10.B8 (SBU2), P10#2.A8 (SBU1), P10#2.B8 (SBU2)
/USB Breakout/10: J5_1.3, J5_1#2.3, P10.A10 (RX2-), P10.B10 (RX1-), P10#2.A10 (RX2-), P10#2.B10 (RX1-)
/USB Breakout/11: J5_1.2, J5_1#2.2, P10.A11 (RX2+), P10.B11 (RX1+), P10#2.A11 (RX2+), P10#2.B11 (RX1+)
/USB Breakout/GND: J5_0.1, J5_0#2.1, P10.A1 (GND), P10.A12 (GND), P10.B1 (GND), P10.B12 (GND), P10.S1 (SHIELD), P10#2.A1 (GND), P10#2.A12 (GND), P10#2.B1 (GND), P10#2.B12 (GND), P10#2.S1 (SHIELD)
/USB Breakout/VBUS: J5_1.1, J5_1#2.1, P10.A4 (VBUS), P10.A9 (VBUS), P10.B4 (VBUS), P10.B9 (VBUS), P10#2.A4 (VBUS), P10#2.A9 (VBUS), P10#2.B4 (VBUS), P10#2.B9 (VBUS)

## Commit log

2025-05-09 Add preliminary PCB design.
    [excelsior.kicad_pcb, excelsior.kicad_sch, excelsior_main.kicad_sch]
2025-05-12 Continue work on PCB design.
    [excelsior.kicad_pcb, excelsior.kicad_sch]
2025-05-13 Continue work on PCBs, add Gerber files.
    [excelsior-B_Cu.gbr, excelsior-B_Mask.gbr, excelsior-B_Paste.gbr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]
2025-05-13 Continue work on PCBs, add gitignore and remove backup files.
    [excelsior.kicad_sch, excelsior_kb2040.kicad_sch, excelsior_pga2350.kicad_sch]
2025-05-14 Continue work on PCBs.
    [excelsior.kicad_pcb, excelsior.kicad_sch, excelsior_kb2040_backub.kicad_sch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]
2025-05-14 Fresh start on PCBs.
    [excelsior-B_Cu.gbr, excelsior-B_Mask.gbr, excelsior-B_Paste.gbr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]
2025-05-15 Add breakout boards for MCP23S17 and HDMI connector.
    [excelsior.kicad_pcb, excelsior.kicad_sch, hdmi_breakout.kicad_pcb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]
2025-05-15 Restructure PCB folder.
    [excelsior.kicad_pcb, excelsior.kicad_sch, hdmi_breakout.kicad_pcb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]
2025-05-20 - Update main Readme. - Add folders for case CAD and KMK files. - In the PCBs, fix VBUS and GND being removed from connectors. - Add PCB readme.
    [excelsior.kicad_pcb, main_board.kicad_sch, peripheral_board.kicad_sch]
2025-05-21 - Change pogo pin connectors on opposite sides from rotated to mirrored. - Add lots of firmware code. - Add VSCode settings to gitignore.
    [excelsior.kicad_pcb]
2025-05-23 Add FreeCAD project for case.
    [case.FCStd]
2025-05-26 Finish main plate except stabilizer cutouts.
    [case.FCStd]
2025-05-29 Add stabilizer cutouts to main plate model.
    [case.FCStd]
2025-06-16 Add boot.py for setting CircuitPython drive name.
